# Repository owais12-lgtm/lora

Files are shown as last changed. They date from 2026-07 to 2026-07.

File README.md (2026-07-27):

# lora
you might ask what is lora?

LoRa modules enable multi-mile wireless communication by using a patented spread spectrum modulation approach developed by Semtech called LoRa. It uses a form of spread spectrum modulation known as Chirp Spread Spectrum (CSS) whose frequency increases or decreases over time across the channel bandwidth 

This LoRa module uses Sub GHz frequencies to transmit and receive messages using sub gigahertzs frequencies of radio waves. below are the compoenents used for this! 

    SX1262IMLTRT for transmission and reception.
    RP2040 for Programing
    0900FM15D0039E as an RF filter.
    AP2112K-3.3 as my LDO.
    PE4259 as my RF switch.
    Two quartz timer crystals (12 MHz and 32 MHz).
    
# PCB pictures





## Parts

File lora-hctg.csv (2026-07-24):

# | Designator | Footprint | Qty | Designation | Supplier & Ref
--- | ------------ | ----------- | :---: | ------------- | ----------------
1 | R3, R2 | R_0402_1005Metric | 2 | 27.4Ω
2 | C16, C17 | C_0402_1005Metric | 2 | 10µF
3 | FB1 | L_0402_1005Metric | 1 | BLM15AX102SN1D
4 | C2, C1 | C_0402_1005Metric | 2 | 100nF
5 | U3 | SOT-363_SC-70-6 | 1 | PE4259
6 | C18 | C_0402_1005Metric | 1 | 39pF
7 | SW3 | SW_SPST_PTS647_Sx70 | 1 | RESET
8 | U6 | SOT-23-5 | 1 | AP2112K-3.3
9 | C10 | C_0402_1005Metric | 1 | 100nF
10 | C19, C20 | C_0402_1005Metric | 2 | 3.3pF
11 | R1 | R_0402_1005Metric | 1 | 100Ω
12 | C5, C4 | C_0402_1005Metric | 2 | 47pF
13 | SW2 | SW_SPST_PTS647_Sx70 | 1 | BOOTSEL
14 | C15, C8, C12, C14, C9, C23, C22, C11, C13 | C_0402_1005Metric | 9 | 100nF
15 | C24 | C_0402_1005Metric | 1 | 100nF
16 | C21, C7 | C_0402_1005Metric | 2 | 1µF
17 | Y1 | Crystal_SMD_3225-4Pin_3.2x2.5mm | 1 | 12MHz
18 | U2 | QFN-56-1EP_7x7mm_P0.4mm_EP3.2x3.2mm | 1 | RP2040
19 | R5 | R_0402_1005Metric | 1 | 1kΩ
20 | L2 | L_0402_1005Metric | 1 | 47nH
21 | J1 | USB_C_Receptacle_G-Switch_GT-USB-7010ASV | 1 | USB_C_Receptacle_USB2.0_16P
22 | U4 | Balun_Johanson_0900FM15K0039 | 1 | 0900FM15D0039E
23 | AE1 | PinSocket_1x01_P2.54mm_Vertical | 1 | Antenna
24 | C6 | C_0402_1005Metric | 1 | 1nF
25 | R6, R7 | R_0402_1005Metric | 2 | 5.1kΩ
26 | U1 | QFN-24-1EP_4x4mm_P0.5mm_EP2.6x2.6mm | 1 | SX1262IMLTRT
27 | C3 | C_0402_1005Metric | 1 | 47nF
28 | L1 | L_0201_0603Metric | 1 | 15µH
29 | R4 | R_0402_1005Metric | 1 | 10kΩ
30 | L3 | L_0402_1005Metric | 1 | 9.1nH
31 | U5 | SOIC-8_5.3x5.3mm_P1.27mm | 1 | W25Q128JVS

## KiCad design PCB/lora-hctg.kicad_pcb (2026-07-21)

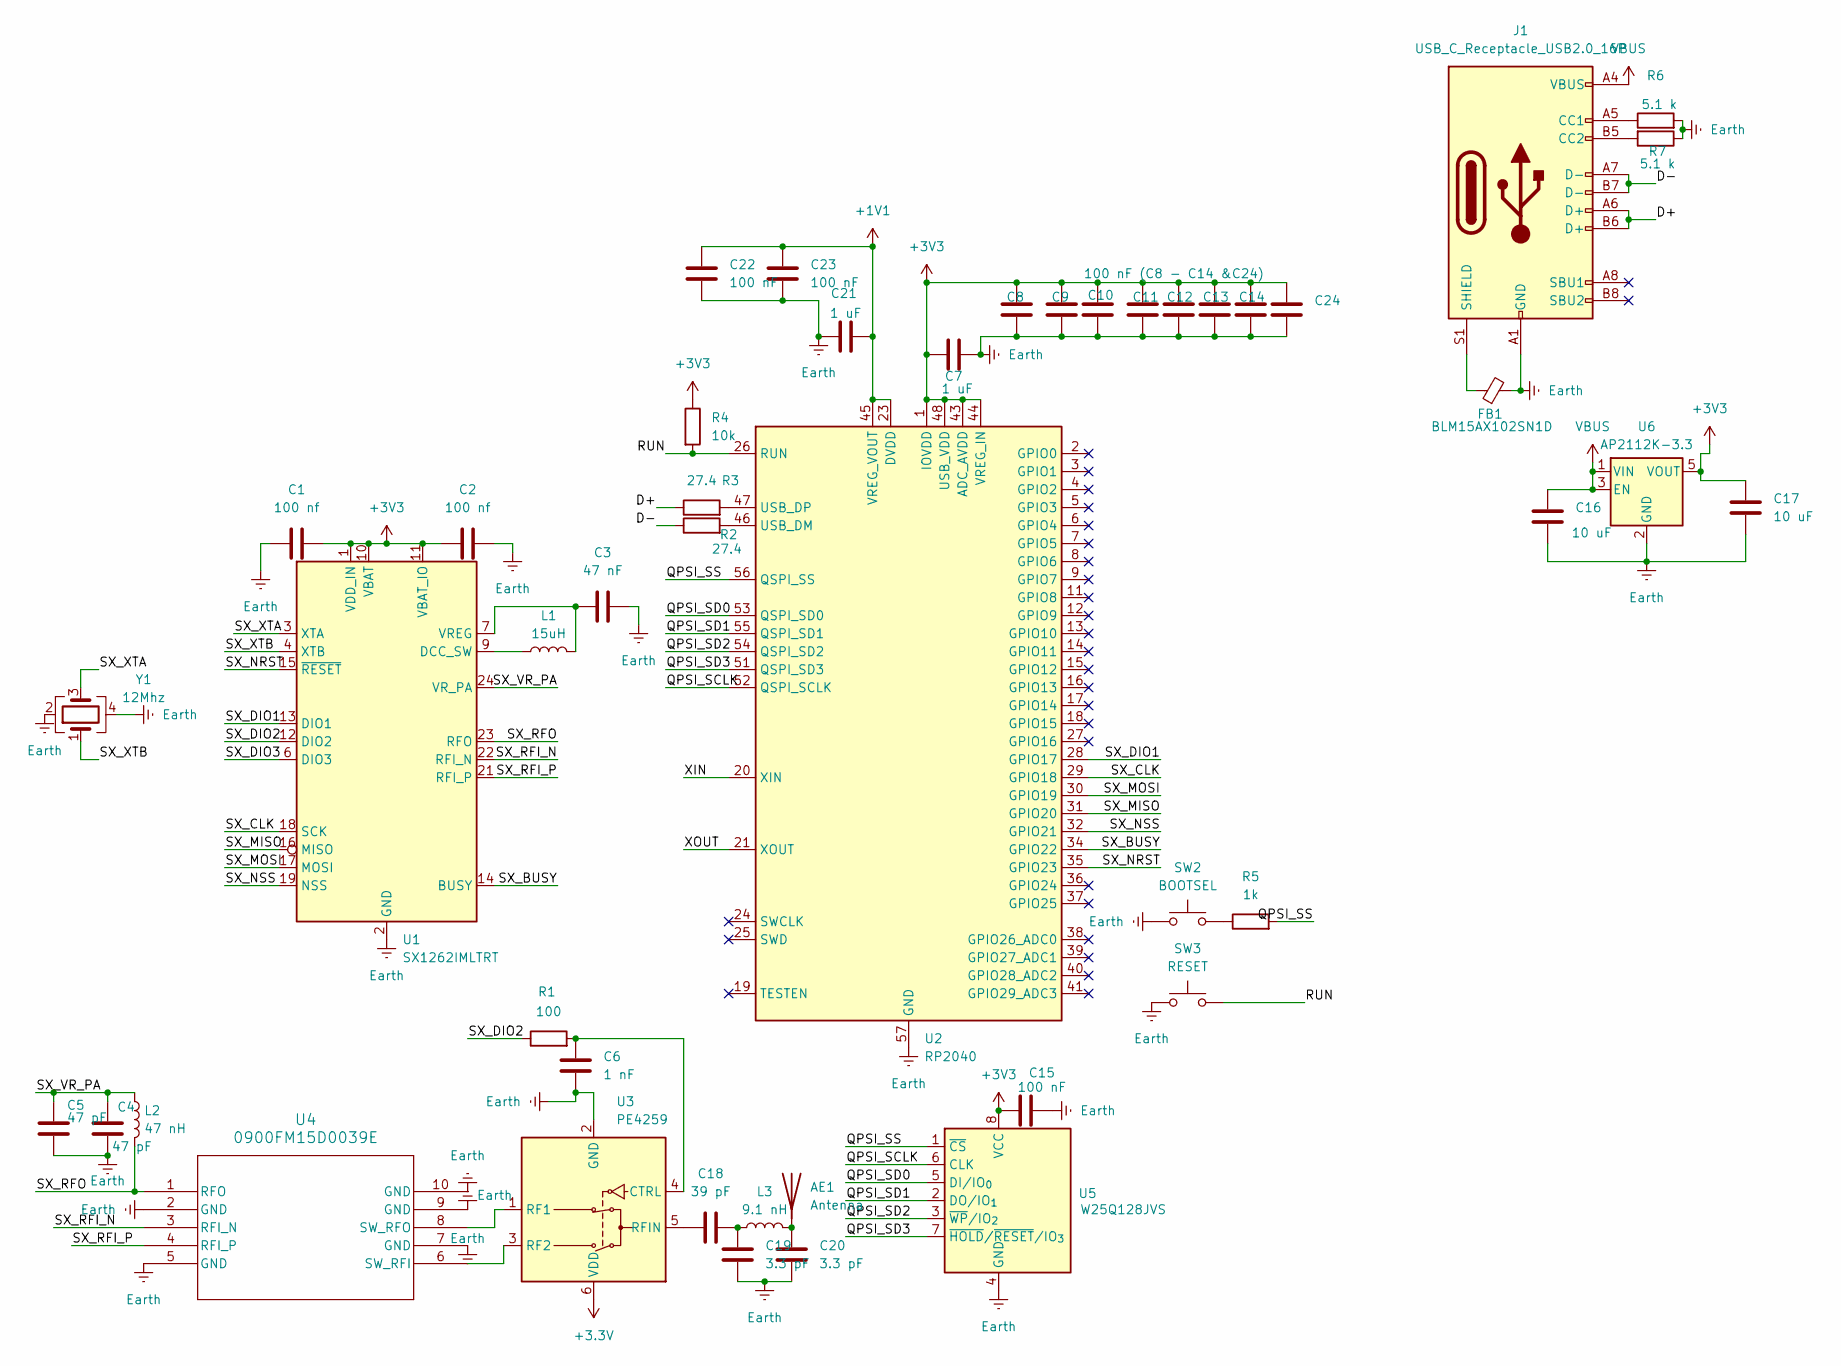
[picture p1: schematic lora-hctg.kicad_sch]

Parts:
AE1: Antenna; PinSocket_1x01_P2.54mm_Vertical
C1, C2: 100 nf; C_0402_1005Metric
C3: 47 nF; C_0402_1005Metric
C4, C5: 47 pF; C_0402_1005Metric
C6: 1 nF; C_0402_1005Metric
C7, C21: 1 uF; C_0402_1005Metric
C8, C9, C11, C12, C13, C14, C15, C22, C23: 100 nF; C_0402_1005Metric
C10: 100 nF (C8 - C14 &C24); C_0402_1005Metric
C16, C17: 10 uF; C_0402_1005Metric
C18: 39 pF; C_0402_1005Metric
C19, C20: 3.3 pF; C_0402_1005Metric
C24: 100nF; C_0402_1005Metric
FB1: BLM15AX102SN1D; L_0402_1005Metric
J1: USB_C_Receptacle_USB2.0_16P; USB_C_Receptacle_G-Switch_GT-USB-7010ASV
L1: 15uH; L_0201_0603Metric
L2: 47 nH; L_0402_1005Metric
L3: 9.1 nH; L_0402_1005Metric
R1: 100; R_0402_1005Metric
R2, R3: 27.4; R_0402_1005Metric
R4: 10k; R_0402_1005Metric
R5: 1k; R_0402_1005Metric
R6, R7: 5.1 k; R_0402_1005Metric
SW2: BOOTSEL; SW_SPST_PTS647_Sx70
SW3: RESET; SW_SPST_PTS647_Sx70
U1: SX1262IMLTRT; QFN-24-1EP_4x4mm_P0.5mm_EP2.6x2.6mm
U2: RP2040; QFN-56-1EP_7x7mm_P0.4mm_EP3.2x3.2mm
U3: PE4259; SOT-363_SC-70-6
U4: 0900FM15D0039E; Balun_Johanson_0900FM15K0039
U5: W25Q128JVS; SOIC-8_5.3x5.3mm_P1.27mm
U6: AP2112K-3.3; SOT-23-5
Y1: 12Mhz; Crystal_SMD_3225-4Pin_3.2x2.5mm

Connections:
+1V1: C21.2, C22.1, C23.1, U2.23 (DVDD), U2.45 (VREG_VOUT), U2.50 (DVDD)
+3.3V: U3.6 (VDD)
+3V3: C1.2, C2.1, C7.1, C8.1, C9.1, C10.1, C11.1, C12.1, C13.1, C14.1, C15.1, C17.1, C24.1, R4.1, U1.1 (VDD_IN), U1.10 (VBAT), U1.11 (VBAT_IO), U2.1 (IOVDD), U2.10 (IOVDD), U2.22 (IOVDD), U2.33 (IOVDD), U2.42 (IOVDD), U2.43 (ADC_AVDD), U2.44 (VREG_IN), U2.48 (USB_VDD), U2.49 (IOVDD), U5.8 (VCC), U6.5 (VOUT)
/D+: J1.A6 (D+), J1.B6 (D+), R3.1
/D-: J1.A7 (D-), J1.B7 (D-), R2.1
/QPSI_SCLK: U2.52 (QSPI_SCLK), U5.6 (CLK)
/QPSI_SD0: U2.53 (QSPI_SD0), U5.5 (DI/IO_{0})
/QPSI_SD1: U2.55 (QSPI_SD1), U5.2 (DO/IO_{1})
/QPSI_SD2: U2.54 (QSPI_SD2), U5.3 (~WP/IO_{2})
/QPSI_SD3: U2.51 (QSPI_SD3), U5.7 (~HOLD/~RESET/IO_{3})
/QPSI_SS: R5.2, U2.56 (QSPI_SS), U5.1 (~CS)
/RUN: R4.2, SW3.2, U2.26 (RUN)
/SX_BUSY: U1.14 (BUSY), U2.34 (GPIO22)
/SX_CLK: U1.18 (SCK), U2.29 (GPIO18)
/SX_DIO1: U1.13 (DIO1), U2.28 (GPIO17)
/SX_DIO2: R1.1, U1.12 (DIO2)
/SX_DIO3: U1.6 (DIO3)
/SX_MISO: U1.16 (MISO), U2.31 (GPIO20)
/SX_MOSI: U1.17 (MOSI), U2.30 (GPIO19)
/SX_NRST: U1.15 (~RESET), U2.35 (GPIO23)
/SX_NSS: U1.19 (NSS), U2.32 (GPIO21)
/SX_RFI_N: U1.22 (RFI_N), U4.3 (RFI_N)
/SX_RFI_P: U1.21 (RFI_P), U4.4 (RFI_P)
/SX_RFO: L2.2, U1.23 (RFO), U4.1 (RFO)
/SX_VR_PA: C4.1, C5.1, L2.1, U1.24 (VR_PA)
/SX_XTA: U1.3 (XTA), Y1.3
/SX_XTB: U1.4 (XTB), Y1.1
/XIN: U2.20 (XIN)
/XOUT: U2.21 (XOUT)
Earth: C1.1, C2.2, C3.2, C4.2, C5.2, C6.2, C7.2, C8.2, C9.2, C10.2, C11.2, C12.2, C13.2, C14.2, C15.2, C16.1, C17.2, C19.2, C20.2, C21.1, C22.2, C23.2, C24.2, FB1.2, J1.A1 (GND), J1.A12 (GND), J1.B1 (GND), J1.B12 (GND), R6.2, R7.1, SW2.1, SW3.1, U1.2 (GND), U1.5 (GND), U1.8 (GND), U1.20 (GND), U1.25 (GND), U2.57 (GND), U3.2 (GND), U4.2 (GND), U4.5 (GND), U4.7 (GND), U4.9 (GND), U4.10 (GND), U5.4 (GND), U6.2 (GND), Y1.2, Y1.4
unnamed: AE1.1 (A), C20.1, L3.2
unnamed: C18.2, C19.1, L3.1
unnamed: J1.A5 (CC1), R6.1
unnamed: J1.B5 (CC2), R7.2
unnamed: FB1.1, J1.S1 (SHIELD)
unnamed: R5.1, SW2.2
unnamed: L1.1, U1.9 (DCC_SW)
unnamed: C3.1, L1.2, U1.7 (VREG)
unnamed: R2.2, U2.46 (USB_DM)
unnamed: R3.2, U2.47 (USB_DP)
unnamed: C6.1, R1.2, U3.4 (CTRL)
unnamed: U3.1 (RF1), U4.8 (SW_RFO)
unnamed: U3.3 (RF2), U4.6 (SW_RFI)
unnamed: C18.1, U3.5 (RFIN)
VBUS: C16.2, J1.A4 (VBUS), J1.A9 (VBUS), J1.B4 (VBUS), J1.B9 (VBUS), U6.1 (VIN), U6.3 (EN)

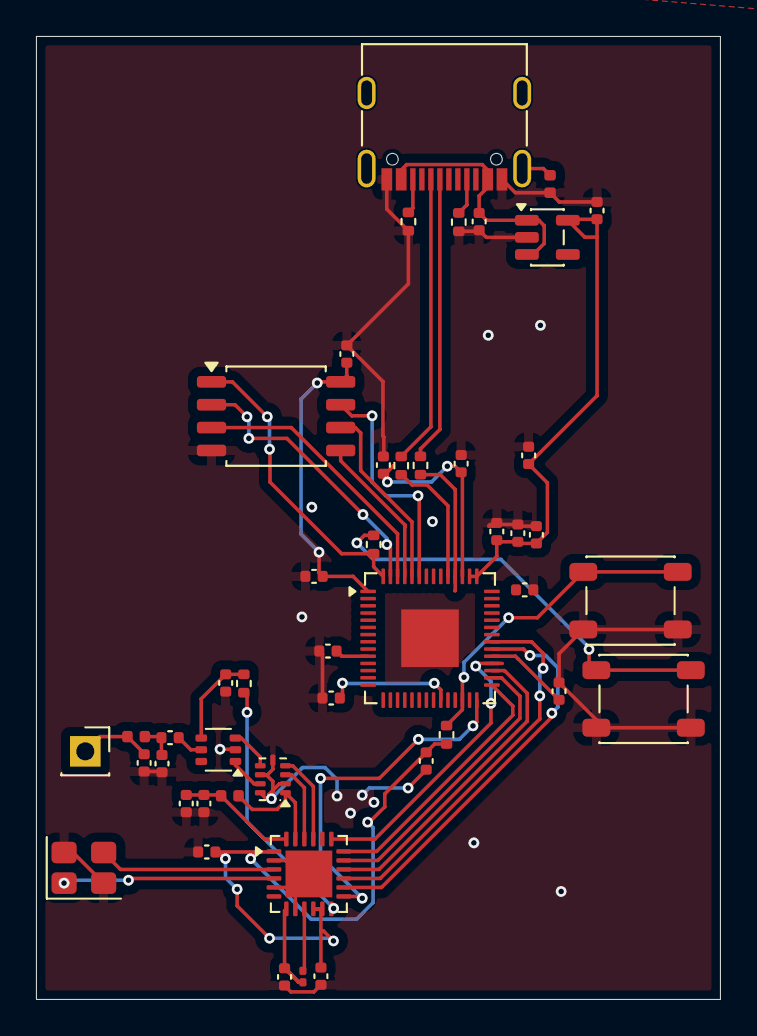
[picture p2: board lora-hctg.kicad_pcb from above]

Board: 2 copper layers, 38.0 x 53.5 mm, 46 parts (0 on the bottom side), 41 nets.

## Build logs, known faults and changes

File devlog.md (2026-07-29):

# total hours spent on project: 25

# Schematic 5.5 hrs



i followed the tutorial on blurprint to make the schematic for the lora module, im using all of these in my schematic, the tutorial contained outdated instructions and symbols for these so i had to ask around slack and stalk other ppl's repos to find what exactly to use 

SX1262IMLTRT 
RP2040 
0900FM15D0039E as an RF filter.
AP2112K-3.3 as my LDO.
PE4259 as my RF switch.
Two quartz timer crystals (12 MHz and 32 MHz).

hrs spent: 5.5 total: 5.5

# more schematic 3 hrs
this is my first time doing rf stuff so im a bit cooked, i had to redo the schematic cuz after 2 month of not working on this. i realised i had a lot of stuff that was not gonna work. like the decoupling capacitors, and a few other parts. lots of them have updated symbols now so i had to upload those too so ive redone this schematic today morning.

hrs spent: 3 total: 8.5



# pcb! 6 hrs 
i just found all the foorprints for this lora module and tried to place this shi and failed a few times. this is the final placemnt i landed on. it was after looking at a buncha lora modules from other ppl, rf needs pretty good placement where stuff is really close to each other.  after this i routed everything so it works properly! during the routing i had to redo it a few times cuz the traces kept colliding and i cant have that if i want this thing to even work. its still really shitty routing im prolly gonna work more on it tonight.

hrs spent: 6 total: 14.5

  

# pcb 2 hrs 
for this devlog i routed the pcb yet again after it started to take up way too much space. the vias were also becoming a problem cuz they wouldnt let the other traces go thru and i'd have to make this a 4 layer pcb and those are not any fun to route.

hrs spent: 2 total: 16.5

 

# fixed all the drc erros! 2.5 hrs
i fixed a lot of clearence erros and traces being too close together, i had to reroute some of the pcb cuz it gave me shit tons of errors. i also missed quite a few of these compoenents so i connectors those too.

 

hrs spent: 2.5 total: 19 hrs

# more pcb stuff 6 hours
i asked soup for some feedback and apparently my routing is dogshit and will not work at all so now im gonna redo the entire routing and placement. most of the issues that seem to be happening with stuff like shielding and routing RF traces. the SX 1262 and both crystals also need to be re routed. souptik seems to think that all my rf stuff is way too far away which i agree with, these r way to far from each other and its usually supposed to be 23 mm wide
time spent: 6 hrs , total:  25 hours

  

  



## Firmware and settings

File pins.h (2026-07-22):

#pragma once

// ===== LED =====
#define PIN_LED         25
#ifndef LED_BUILTIN
#define LED_BUILTIN     PIN_LED
#endif

// ===== UART =====
#define PIN_SERIAL_TX   0     // USB/UART TX
#define PIN_SERIAL_RX   1     // USB/UART RX

// ===== I2C =====
#define PIN_WIRE_SDA    8
#define PIN_WIRE_SCL    9

// ===== SPI (LoRa SX1262) =====
#define PIN_SPI_SCK     2
#define PIN_SPI_MOSI    3
#define PIN_SPI_MISO    4
#define PIN_LORA_NSS    5     // Chip select
#define PIN_LORA_DIO1   6
#define PIN_LORA_BUSY   7
#define PIN_LORA_RESET  22

// ===== RF switch =====
#define PIN_RF_SWITCH   10

// ===== ADC =====
#define PIN_A0          26
#define PIN_A1          27
#define PIN_A2          28

// ===== Debug pins =====
#define PIN_SWCLK       24
#define PIN_SWDIO       25

// ===== Default interfaces =====
#define SERIAL_PORT_MONITOR   Serial
#define SERIAL_PORT_HARDWARE  Serial1 
